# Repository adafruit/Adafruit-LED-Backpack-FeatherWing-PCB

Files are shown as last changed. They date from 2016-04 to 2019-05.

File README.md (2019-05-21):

## Adafruit LED Backpack FeatherWing PCB
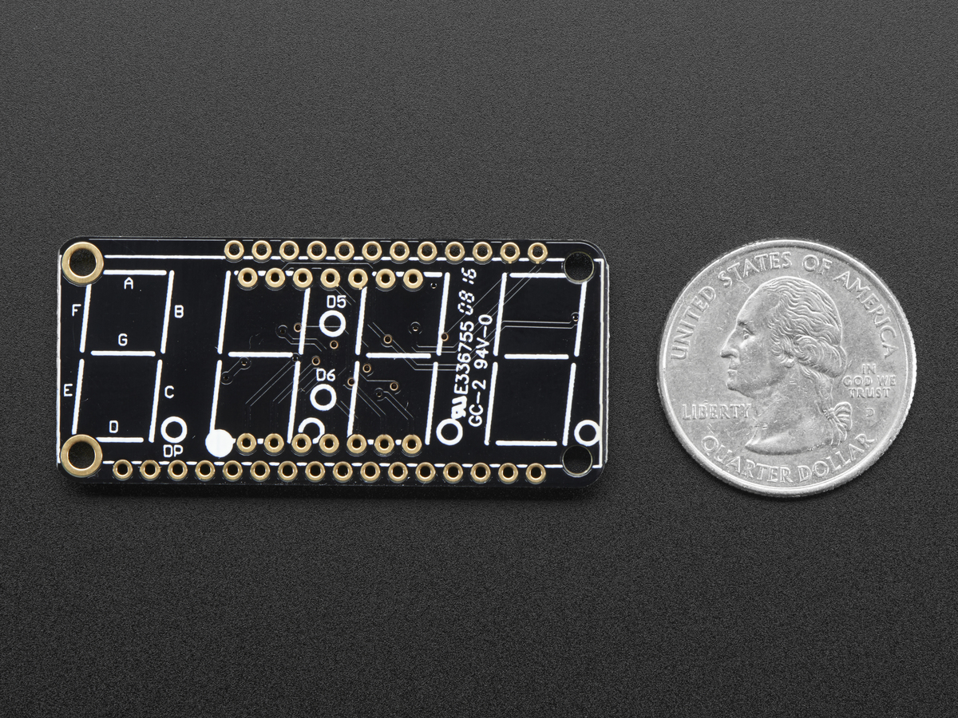
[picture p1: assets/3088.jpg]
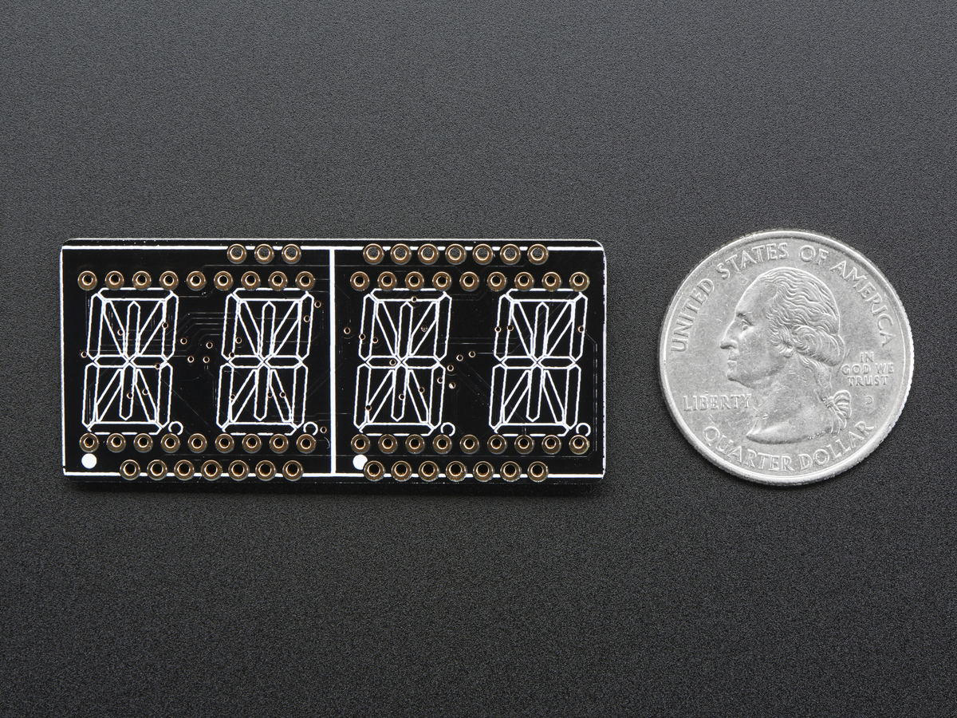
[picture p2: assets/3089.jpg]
&nbsp; <br />
Click to purchase from the Adafruit Shop:
- [Adafruit 4-Digit 7-Segment LED Matrix Display FeatherWing](https://www.adafruit.com/product/3088)
- [Adafruit 14-Segment Alphanumeric LED FeatherWing](https://www.adafruit.com/product/3089)

These are the Eagle CAD files for the Adafruit LED FeatherWings Backpack breakouts:

### 7-segment

This is the Adafruit 4-Digit 7-Segment LED Matrix Display FeatherWing! This 7-segment FeatherWing backpack makes it really easy to add a 4-digit numeric display with decimal points and even 'second colon dots' for making a clock.

This version does not come with an LED matrix. Its also available in combo packs of Blue, Green, Red, White, or Yellow which we recommend since you'll know you have a working LED matrix. Not guaranteed to work with any other 7-segment modules.

- http://www.adafruit.com/products/3088
- http://www.adafruit.com/products/3106
- http://www.adafruit.com/products/3107
- http://www.adafruit.com/products/3108
- http://www.adafruit.com/products/3109
- http://www.adafruit.com/products/3110

### 14-segment

This is the Adafruit 0.56" 4-Digit 14-Segment Display FeatherWing! This 14-segment FeatherWing backpack makes it really easy to add a bright alphanumeric display that shows letters and numbers in a beautiful hue. It's super bright and designed for viewing from distances up to 23 feet (7 meters) away.

14-Segment Matrices like these are 'multiplexed' - so to control all the fourteen-segment LEDs you need 18 pins. That's a lot of pins, and there are driver chips like the MAX7219 that can control a matrix for you but there's a lot of wiring to set up and they take up a ton of space. Wouldn't it be awesome if you could control a matrix without tons of wiring? That's where these Alphanumeric LED Matrix FeatherWings come in, they make it really easy to add a 4-digit alphanumeric display with decimal points.

- http://www.adafruit.com/products/3089
- http://www.adafruit.com/products/3127
- http://www.adafruit.com/products/3128
- http://www.adafruit.com/products/3129
- http://www.adafruit.com/products/3130
- http://www.adafruit.com/products/3131
- http://www.adafruit.com/products/3132

These displays use I2C to communicate, 2 pins are required to 
interface. There are multiple selectable I2C addresses. For backpacks 
with 3 Address Select pins: 0x70 thru 0x77

### License

Adafruit invests time and resources providing this open source design, please support Adafruit and open-source hardware by [purchasing products from Adafruit](https://www.adafruit.com)!

All text above must be included in any redistribution

Designed by Limor Fried/Ladyada for Adafruit Industries.
Creative Commons Attribution/Share-Alike, all text above must be included in any redistribution. 
See license.txt for additional information.

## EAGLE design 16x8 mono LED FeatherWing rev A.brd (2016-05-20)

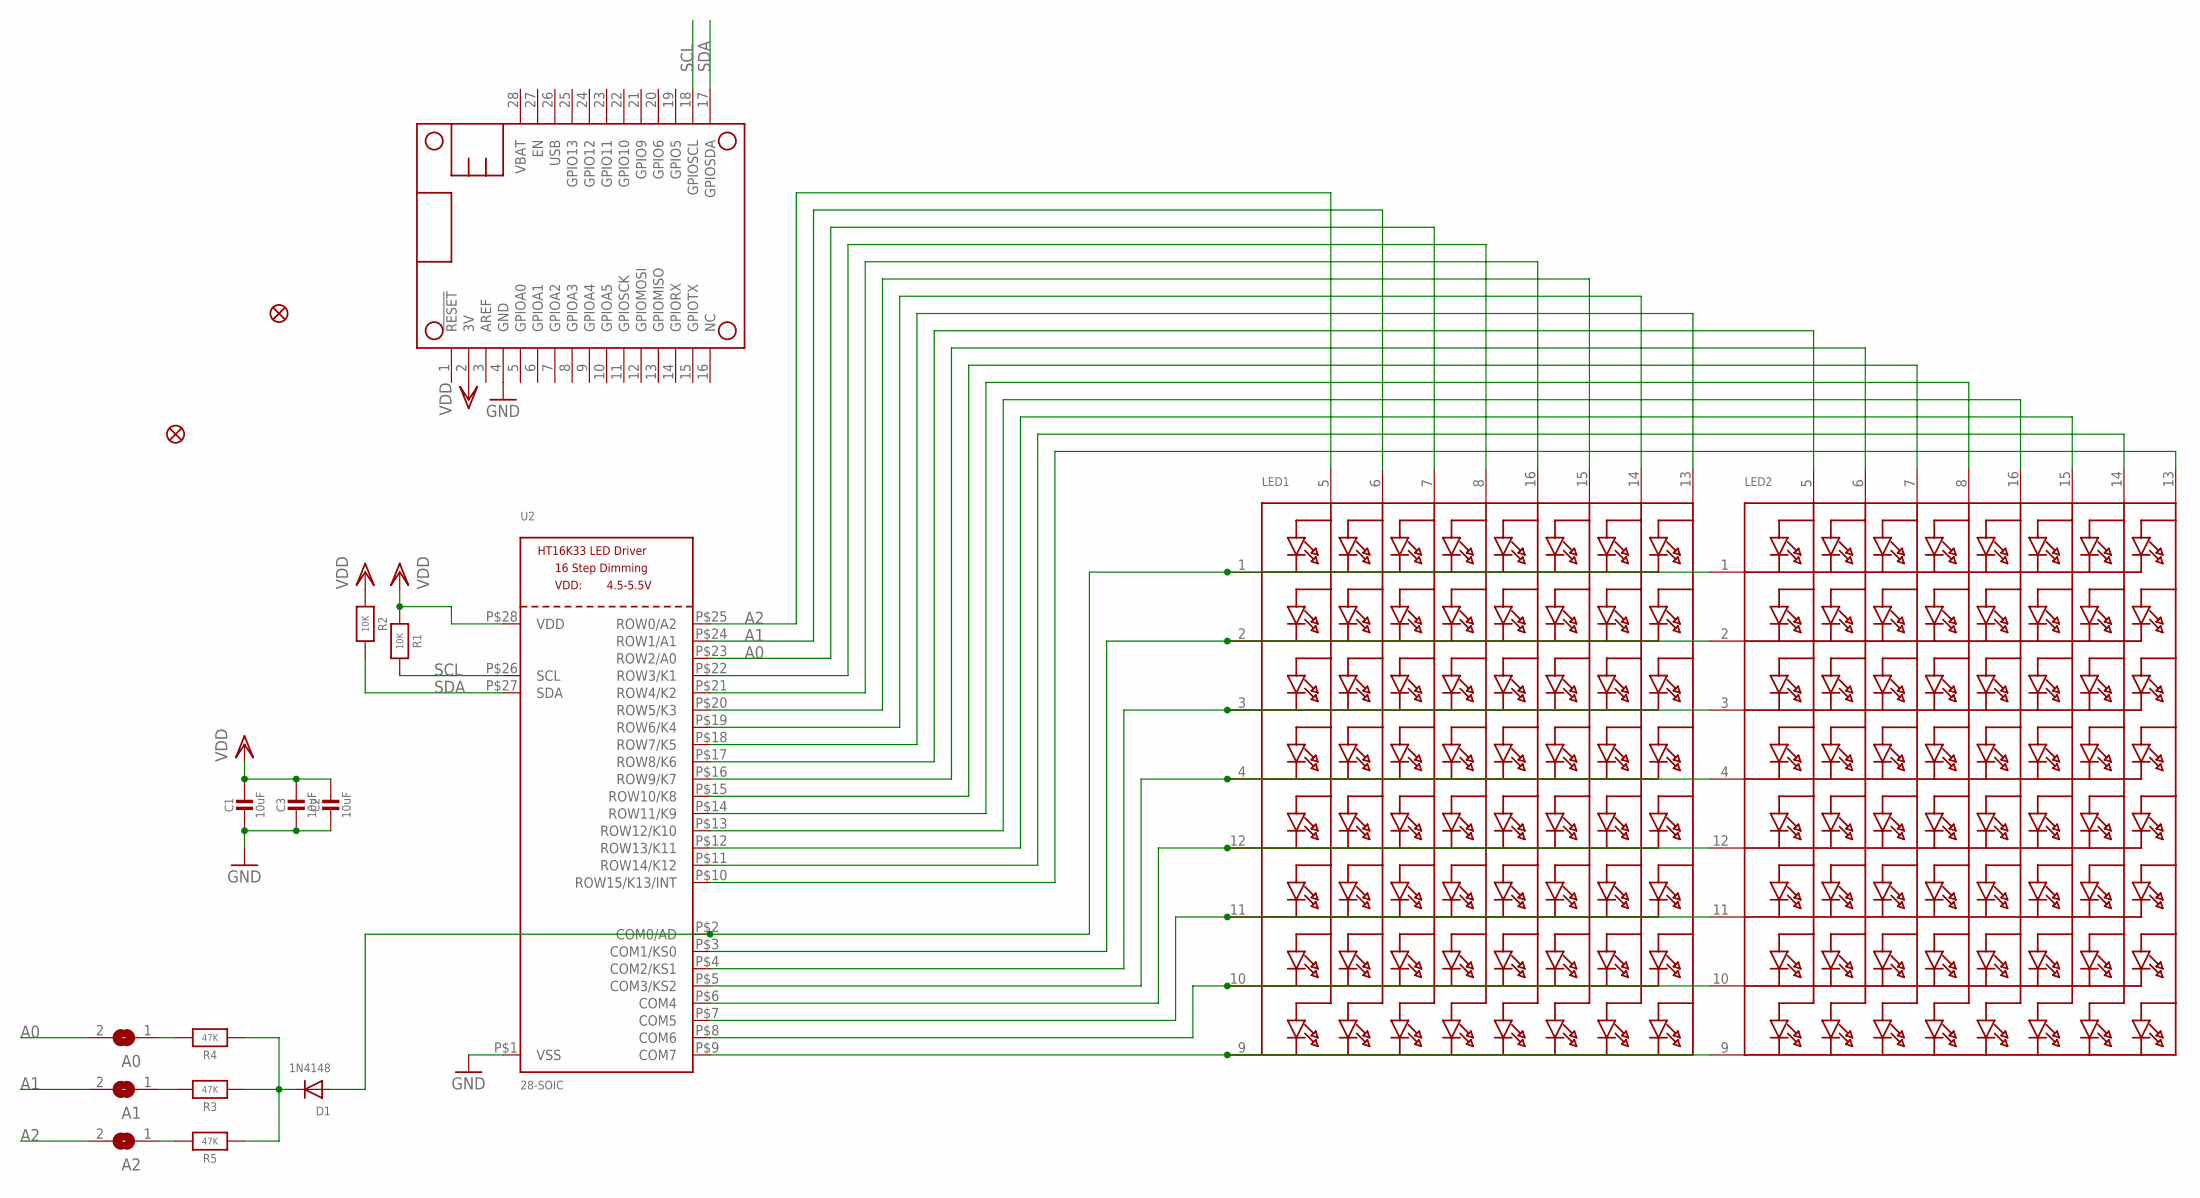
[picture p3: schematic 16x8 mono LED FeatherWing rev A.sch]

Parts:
A0, A1, A2: SOLDERJUMPERREFLOW_NOPASTE; SOLDERJUMPER_REFLOW_NOPASTE
C1, C2, C3: 10uF; 0805-NO
D1: 1N4148; SOD-323F
FID1, FID2: FIDUCIAL""; FIDUCIAL_1MM
LED1, LED2: DISP_SEGMENT_8X8_ROWCATHODE; SEGMENT_BL-M07C881UR
MS1: FEATHERWING
R1, R2: 10K; 0805-NO
R3, R4, R5: 47K; 0805-NO
U2: 28-SOIC; SOP28_300MIL_SKINNY

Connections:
A0: A0.2, LED1.7 (A3), U2.P$23 (ROW2/A0)
A1: A1.2, LED1.6 (A2), U2.P$24 (ROW1/A1)
A2: A2.2, LED1.5 (A1), U2.P$25 (ROW0/A2)
GND: C1.2, C2.2, C3.2, MS1.4 (GND), U2.P$1 (VSS)
unnamed: LED1.9 (K8), LED2.9 (K8), U2.P$9 (COM7)
unnamed: LED1.10 (K7), LED2.10 (K7), U2.P$8 (COM6)
unnamed: LED1.11 (K6), LED2.11 (K6), U2.P$7 (COM5)
unnamed: LED1.12 (K5), LED2.12 (K5), U2.P$6 (COM4)
unnamed: LED1.4 (K4), LED2.4 (K4), U2.P$5 (COM3/KS2)
unnamed: LED1.3 (K3), LED2.3 (K3), U2.P$4 (COM2/KS1)
unnamed: LED1.2 (K2), LED2.2 (K2), U2.P$3 (COM1/KS0)
unnamed: D1.A, LED1.1 (K1), LED2.1 (K1), U2.P$2 (COM0/AD)
unnamed: A2.1, R5.2
unnamed: LED2.14 (A7), U2.P$11 (ROW14/K12)
unnamed: LED2.15 (A6), U2.P$12 (ROW13/K11)
unnamed: LED2.13 (A8), U2.P$10 (ROW15/K13/INT)
unnamed: D1.C, R3.1, R4.1, R5.1
unnamed: A1.1, R3.2
unnamed: A0.1, R4.2
unnamed: LED1.13 (A8), U2.P$18 (ROW7/K5)
unnamed: LED1.14 (A7), U2.P$19 (ROW6/K4)
unnamed: LED1.16 (A5), U2.P$21 (ROW4/K2)
unnamed: LED1.8 (A4), U2.P$22 (ROW3/K1)
unnamed: LED1.15 (A6), U2.P$20 (ROW5/K3)
unnamed: LED2.5 (A1), U2.P$17 (ROW8/K6)
unnamed: LED2.6 (A2), U2.P$16 (ROW9/K7)
unnamed: LED2.8 (A4), U2.P$14 (ROW11/K9)
unnamed: LED2.7 (A3), U2.P$15 (ROW10/K8)
unnamed: LED2.16 (A5), U2.P$13 (ROW12/K10)
SCL: MS1.18 (GPIOSCL), R1.2, U2.P$26 (SCL)
SDA: MS1.17 (GPIOSDA), R2.2, U2.P$27 (SDA)
VDD: C1.1, C2.1, C3.1, MS1.2 (3V), R1.1, R2.1, U2.P$28 (VDD)

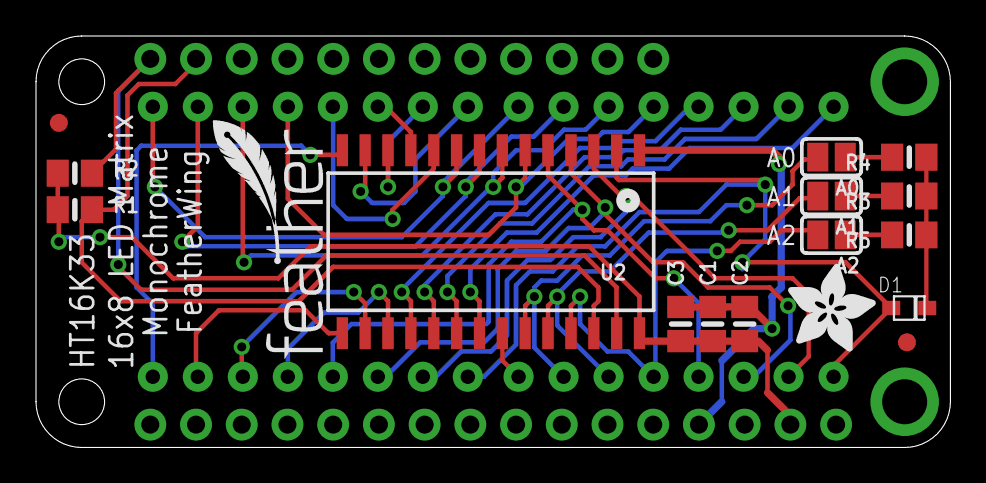
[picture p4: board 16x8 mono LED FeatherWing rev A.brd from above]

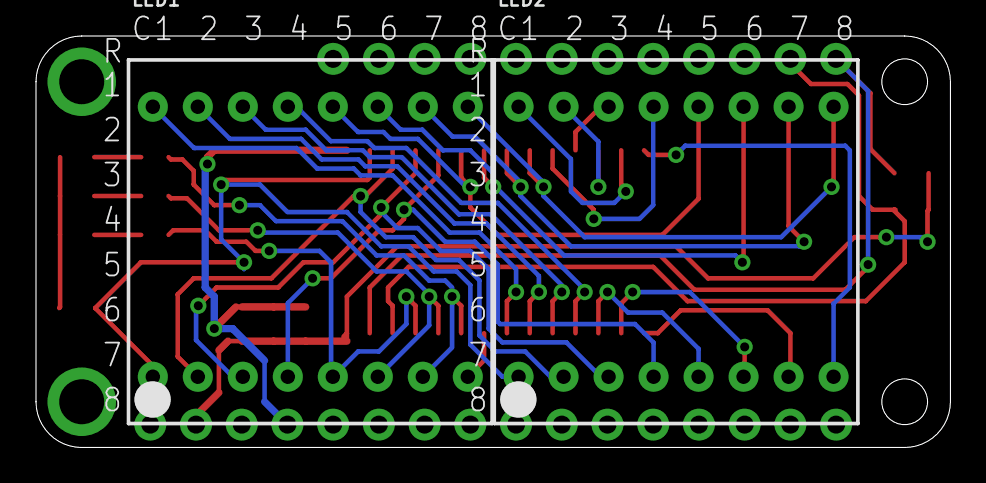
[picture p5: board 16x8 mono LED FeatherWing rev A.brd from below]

Board: 2 copper layers, 50.8 x 22.9 mm, 20 parts (3 on the bottom side), 32 nets.

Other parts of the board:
U$1: FEATHERLOGO_SMALL
U$2: ADAFRUIT_5MM

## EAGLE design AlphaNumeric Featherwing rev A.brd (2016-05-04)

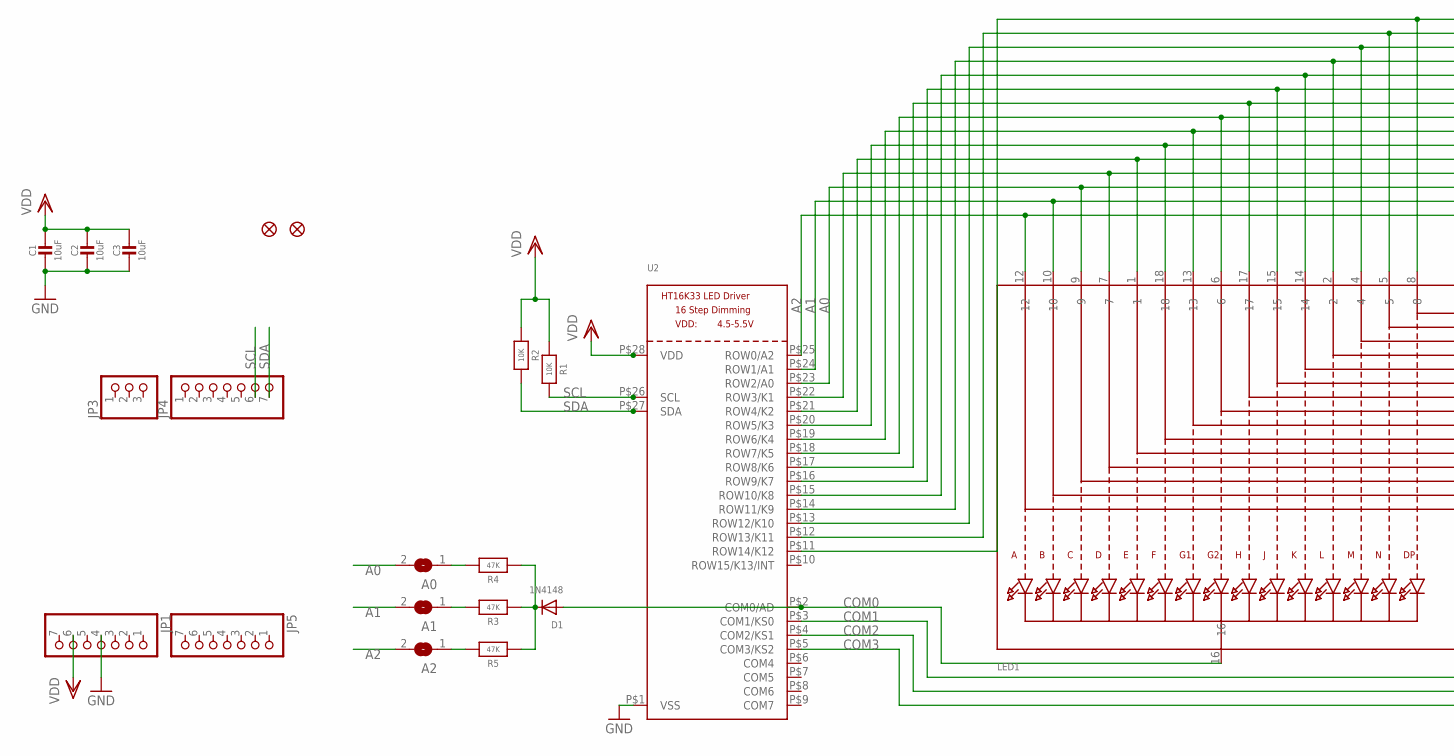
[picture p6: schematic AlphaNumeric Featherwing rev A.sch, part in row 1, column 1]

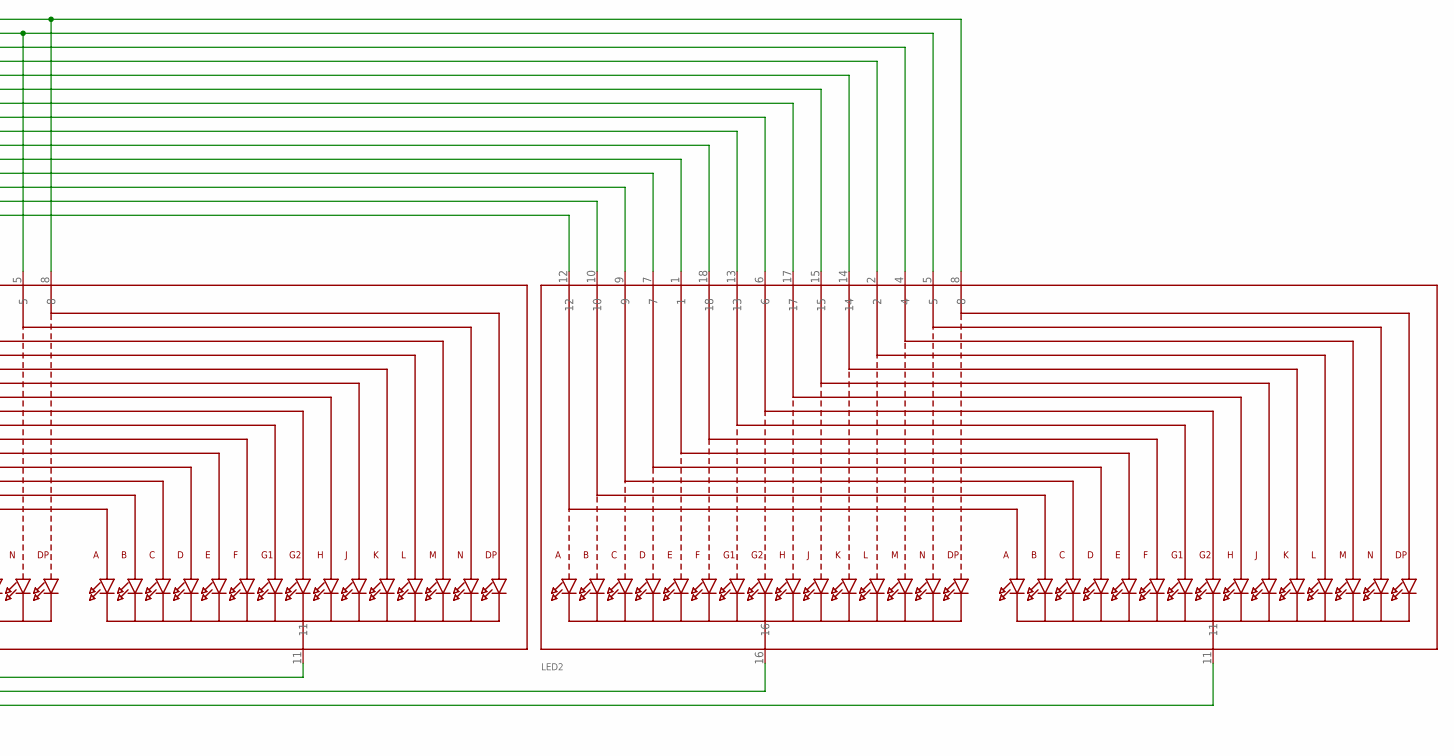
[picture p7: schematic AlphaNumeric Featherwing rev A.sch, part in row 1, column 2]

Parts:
A0, A1, A2: SOLDERJUMPERREFLOW_NOPASTE; SOLDERJUMPER_REFLOW_NOPASTE
C1, C2, C3: 10uF; 0805-NO
D1: 1N4148; SOD-323F
JP1, JP4, JP5: HEADER-1X770MIL; 1X07_ROUND_70
JP3: HEADER-1X3ROUND; 1X03_ROUND
LED1, LED2: DISP_SEGMENT_STARBURST_DUAL_COMMONCATHODE; SEGMENT_STARTBUST_DUAL_KWA-541CBB
R1, R2: 10K; 0805-NO
R3, R4, R5: 47K; 0805-NO
U2: HT16K33_SOP28_SKINNY; SOP28_300MIL_SKINNY
U$1, U$2: FIDUCIAL""; FIDUCIAL_1MM

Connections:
A0: A0.2, LED1.9, LED2.9, U2.P$23 (ROW2/A0)
A1: A1.2, LED1.10, LED2.10, U2.P$24 (ROW1/A1)
A2: A2.2, LED1.12, LED2.12, U2.P$25 (ROW0/A2)
COM0: D1.A, LED1.16, U2.P$2 (COM0/AD)
COM1: LED1.11, U2.P$3 (COM1/KS0)
COM2: LED2.16, U2.P$4 (COM2/KS1)
COM3: LED2.11, U2.P$5 (COM3/KS2)
GND: C1.2, C2.2, C3.2, JP1.4, U2.P$1 (VSS)
unnamed: D1.C, R3.1, R4.1, R5.1
unnamed: LED1.17, LED2.17, U2.P$17 (ROW8/K6)
unnamed: LED1.15, LED2.15, U2.P$16 (ROW9/K7)
unnamed: LED1.14, LED2.14, U2.P$15 (ROW10/K8)
unnamed: A2.1, R5.2
unnamed: LED1.2, LED2.2, U2.P$14 (ROW11/K9)
unnamed: LED1.4, LED2.4, U2.P$13 (ROW12/K10)
unnamed: LED1.7, LED2.7, U2.P$22 (ROW3/K1)
unnamed: LED1.1, LED2.1, U2.P$21 (ROW4/K2)
unnamed: LED1.18, LED2.18, U2.P$20 (ROW5/K3)
unnamed: LED1.13, LED2.13, U2.P$19 (ROW6/K4)
unnamed: LED1.5, LED2.5, U2.P$12 (ROW13/K11)
unnamed: LED1.8, LED2.8, U2.P$11 (ROW14/K12)
unnamed: LED1.6, LED2.6, U2.P$18 (ROW7/K5)
unnamed: A1.1, R3.2
unnamed: A0.1, R4.2
SCL: JP4.6, R1.2, U2.P$26 (SCL)
SDA: JP4.7, R2.2, U2.P$27 (SDA)
VDD: C1.1, C2.1, C3.1, JP1.6, R1.1, R2.1, U2.P$28 (VDD)

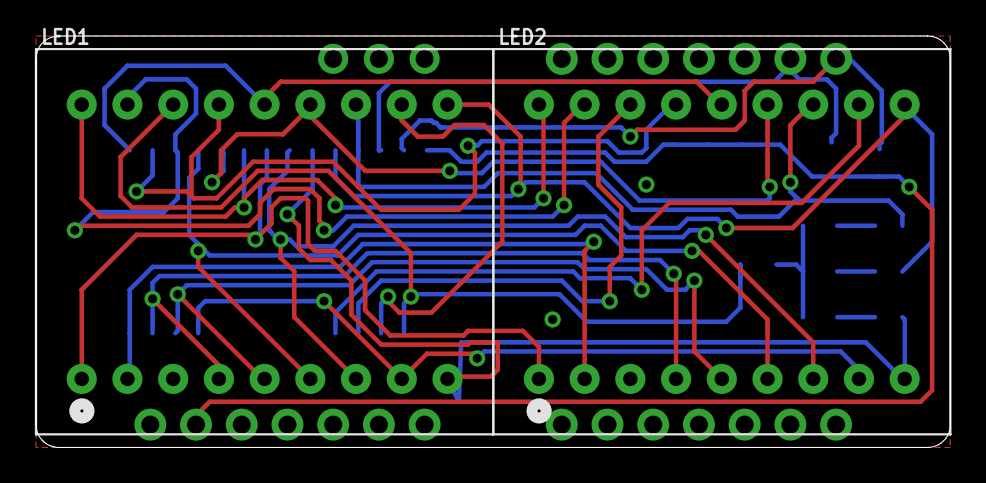
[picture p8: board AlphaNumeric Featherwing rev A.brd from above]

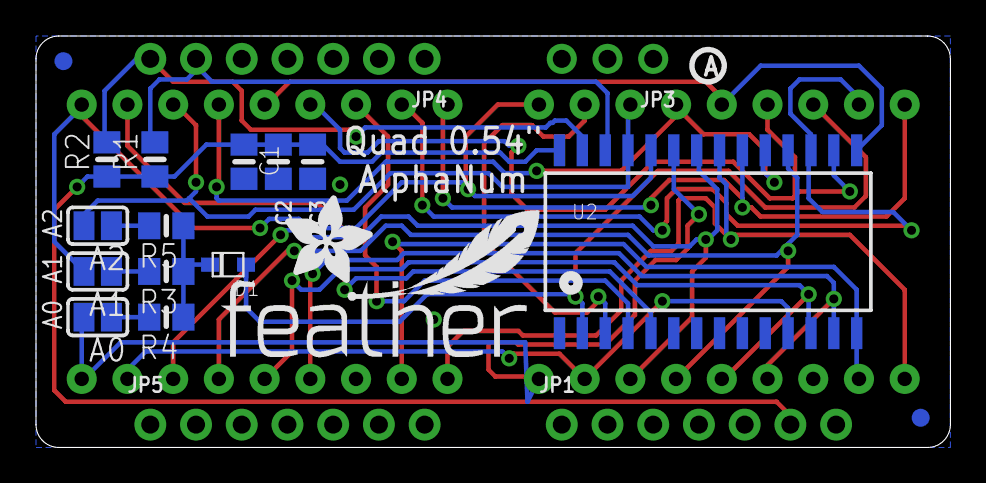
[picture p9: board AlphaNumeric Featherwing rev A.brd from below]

Board: 2 copper layers, 50.8 x 22.9 mm, 24 parts (22 on the bottom side), 27 nets.

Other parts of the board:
U$3: PCBFEAT-REV-040
U$4: FEATHERLOGO_MED
U$5: ADAFRUIT_5MM

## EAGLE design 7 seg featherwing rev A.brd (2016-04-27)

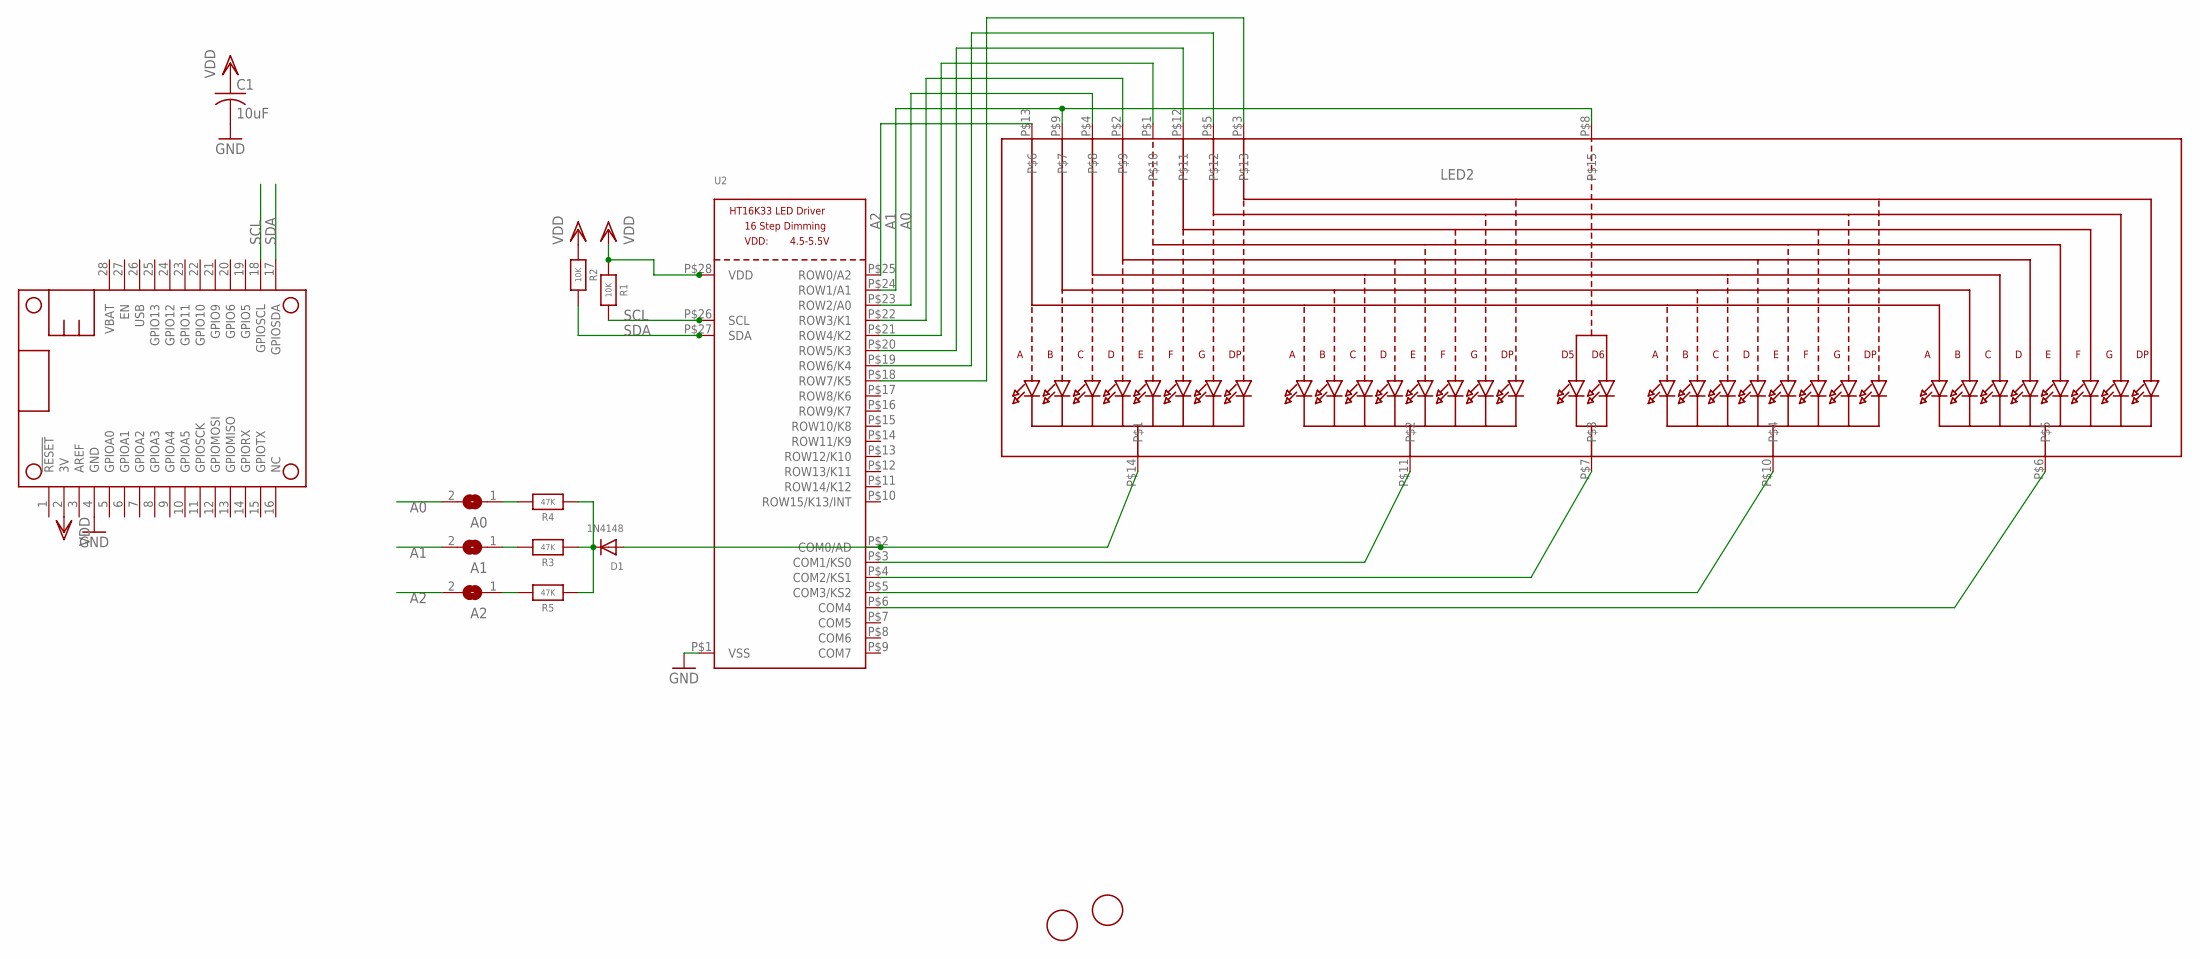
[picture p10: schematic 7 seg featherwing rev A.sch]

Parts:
A0, A1, A2: SOLDERJUMPERREFLOW_NOPASTE; SOLDERJUMPER_REFLOW_NOPASTE
C1: 10uF; C0805K
D1: 1N4148; SOD-323F
LED2: DISP_SEGMENT_4DIGIT_BL-Q56C43; SEGMENT-BL-Q56C43
MS1: FEATHERWING
R1, R2: 10K; 0805-NO
R3, R4, R5: 47K; 0805-NO
U2: HT16K33_SOP28_SKINNY; SOP28_300MIL_SKINNY
U$1, U$2: FIDUCIAL; FIDUCIAL_1MM

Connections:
A0: A0.2, LED2.P$4, U2.P$23 (ROW2/A0)
A1: A1.2, LED2.P$8, LED2.P$9, U2.P$24 (ROW1/A1)
A2: A2.2, LED2.P$13, U2.P$25 (ROW0/A2)
GND: C1.2, MS1.4 (GND), U2.P$1 (VSS)
unnamed: D1.C, R3.1, R4.1, R5.1
unnamed: D1.A, LED2.P$14, U2.P$2 (COM0/AD)
unnamed: LED2.P$11, U2.P$3 (COM1/KS0)
unnamed: LED2.P$7, U2.P$4 (COM2/KS1)
unnamed: LED2.P$10, U2.P$5 (COM3/KS2)
unnamed: LED2.P$6, U2.P$6 (COM4)
unnamed: A2.1, R5.2
unnamed: LED2.P$2, U2.P$22 (ROW3/K1)
unnamed: LED2.P$1, U2.P$21 (ROW4/K2)
unnamed: LED2.P$12, U2.P$20 (ROW5/K3)
unnamed: LED2.P$5, U2.P$19 (ROW6/K4)
unnamed: LED2.P$3, U2.P$18 (ROW7/K5)
unnamed: A1.1, R3.2
unnamed: A0.1, R4.2
SCL: MS1.18 (GPIOSCL), R1.2, U2.P$26 (SCL)
SDA: MS1.17 (GPIOSDA), R2.2, U2.P$27 (SDA)
VDD: C1.1, MS1.2 (3V), R1.1, R2.1, U2.P$28 (VDD)

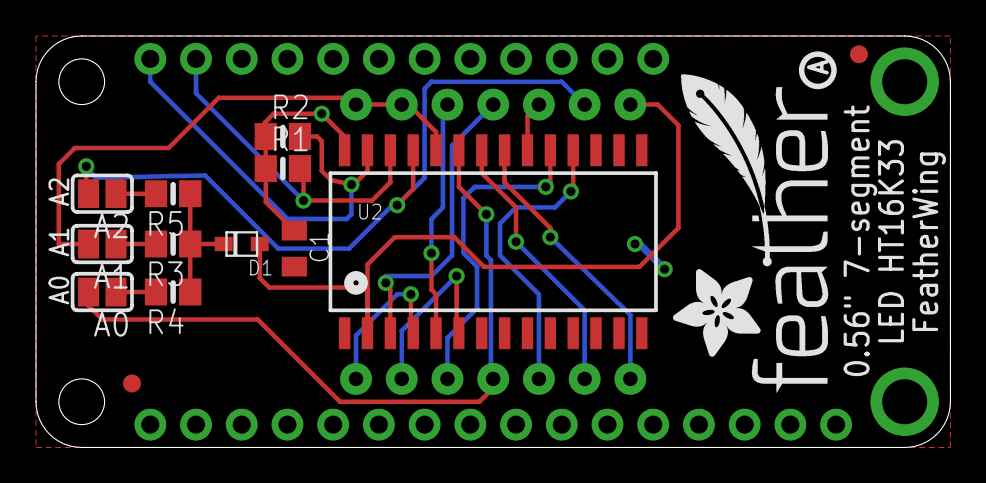
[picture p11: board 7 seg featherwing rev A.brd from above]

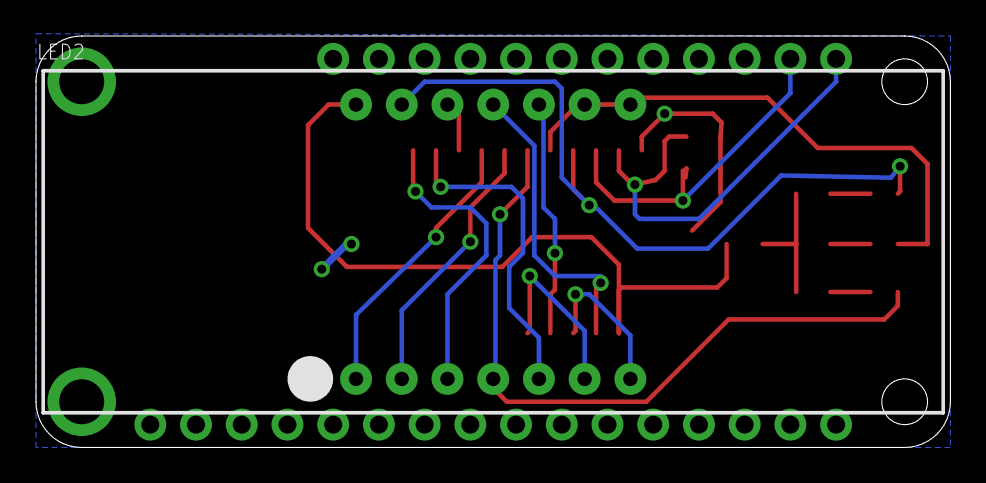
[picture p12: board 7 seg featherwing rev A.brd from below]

Board: 2 copper layers, 50.8 x 22.9 mm, 18 parts (2 on the bottom side), 21 nets.

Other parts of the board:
U$3: ADAFRUIT_5MM
U$4: PCBFEAT-REV-040
U$5: FEATHERLOGO_MED
